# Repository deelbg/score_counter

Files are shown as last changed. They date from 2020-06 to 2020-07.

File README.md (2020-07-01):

# score_counter

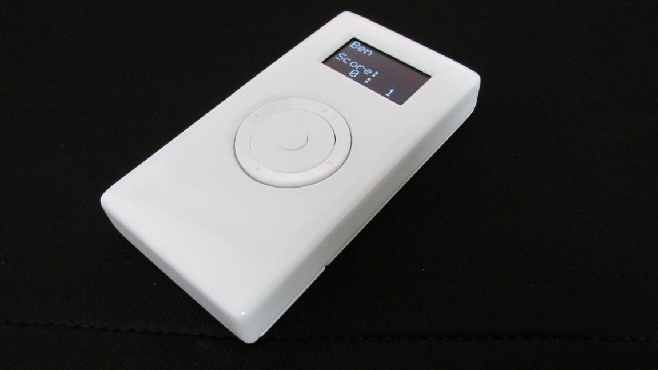
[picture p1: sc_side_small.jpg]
Score Counter


[Also available on my online store.](https://www.tindie.com/stores/deyantodorov/)

  Board games Score Counter is a device meant to be used for keeping the score for up to four players when playing board games like Scrabble etc. The numbers of players is selectable through the settings menu. Names up to ten characters long can be entered for each player.
  For each player an accumulated score is stored, which is the total amount of points up to the current moment in the game, and the points from the current round are entered using a rotary encoder or the Up and Down arrow keys. When OK is pressed the point from the current round are added to the total amount. 
  More detailed explanation and screenshot might be found in the User manual [HERE](https://github.com/deelbg/score_counter/blob/master/sc_manual.pdf) or on my web site [HERE](https://deyantodorov.com/2020/06/24/board-games-score-counter/)
  
Main features.
* Small size (10cm / 5.5cm / 1.7cm). 
* Battery powered. Runs on two AAA batteries.
* 1.3” OLED screen.
* Controlled via five buttons and a rotary switch.
* 3D printed enclosure.
* Energy independent memory to store settings and player names.

In the **/firmware** directory is located the firmware. It uses the drivers from my [SSD1306_SH1106_i2c_text_display](https://github.com/deelbg/SSD1306_SH1106_i2c_text_display) and [hal_lib_avr_cpp](https://github.com/deelbg/hal_lib_avr_cpp) repositories. 
The device is based on a Attiny861 microcontroller.

There is a makefile included. Run the folowing:
* make - to build the project
* clean - to delete object files
* size - to see the used RAM and flash.
* flash - to write the .hex file to the microcontroller. Using avrdude and a usbasp programmer.
* eeprom - to write the eeprom.
* fuse - to write the fuses.

In the **/hardware** directory is located the hardware project for EagleCad and a KiCad export. 
**NOTE:** A 10kOhm pullup resistor needs to be added to the OK button (the one right in the center).  

In the **/enclosure** directory is located a FreeCad project containig the enclosure. The 3 parts are also exported in .obj files that can be directly imported in Cura and sliced for 3d printing.

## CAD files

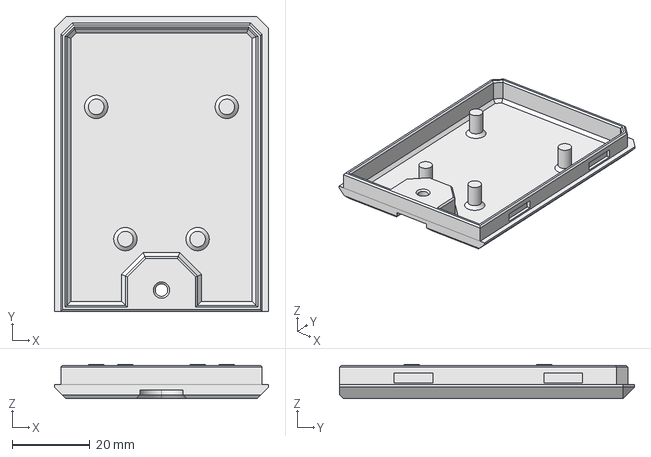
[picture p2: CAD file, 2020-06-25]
enclosure/enclosure_back.fcstd
55.0 x 75.8 x 8.85 mm

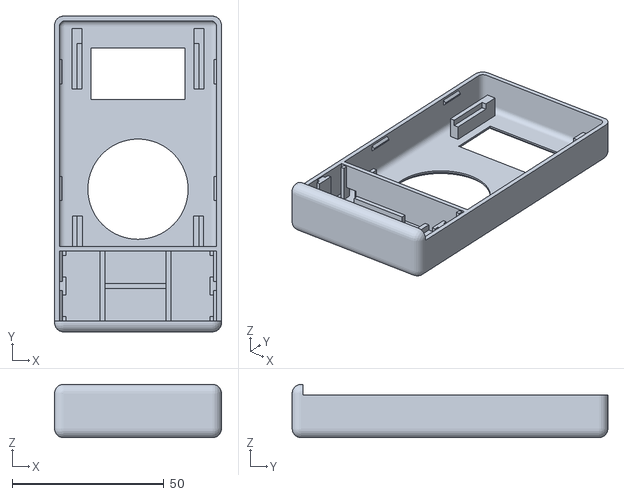
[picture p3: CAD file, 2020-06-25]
enclosure/front_filets.obj
55.0 x 104.0 x 17.6

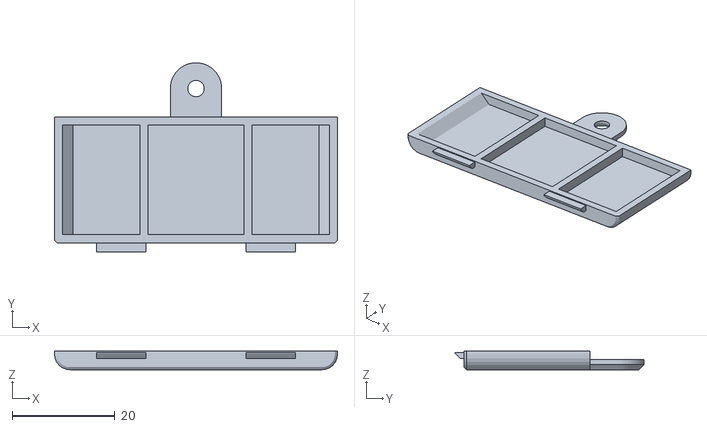
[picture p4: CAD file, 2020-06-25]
enclosure/lid_fillet.obj
55.0 x 36.8 x 3.60

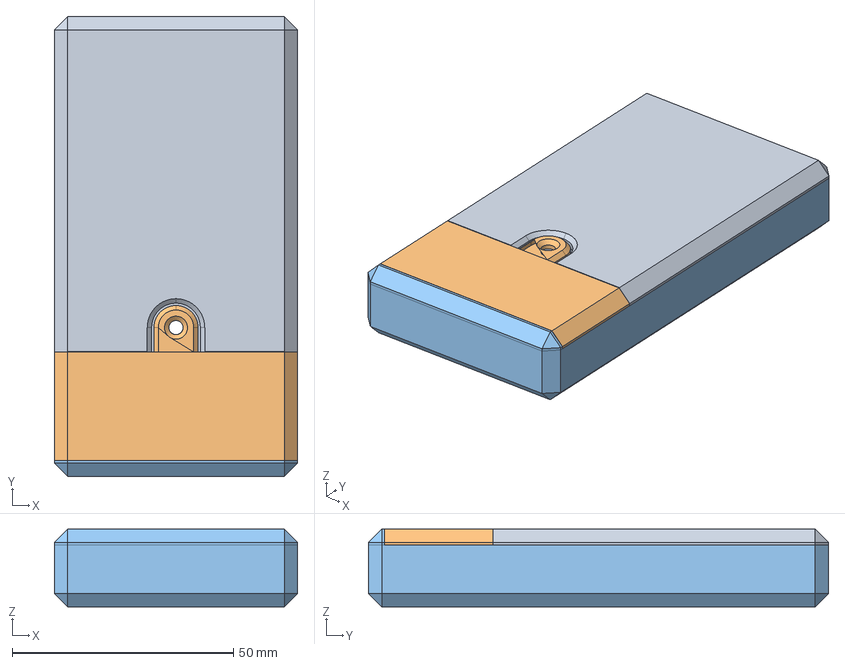
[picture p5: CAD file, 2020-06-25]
enclosure/enclosure.fcstd
55.0 x 104.0 x 17.6 mm

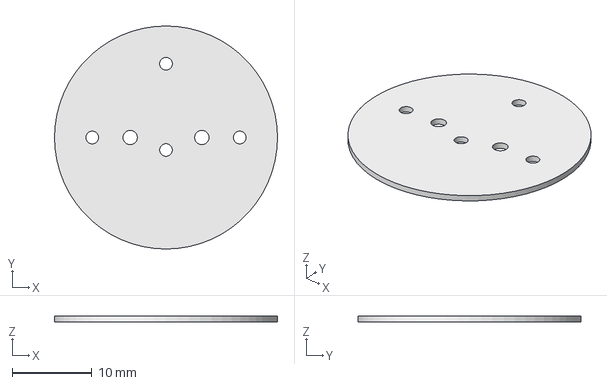
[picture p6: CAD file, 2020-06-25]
enclosure/button_spacer.fcstd
28.0 x 28.0 x 0.7 mm

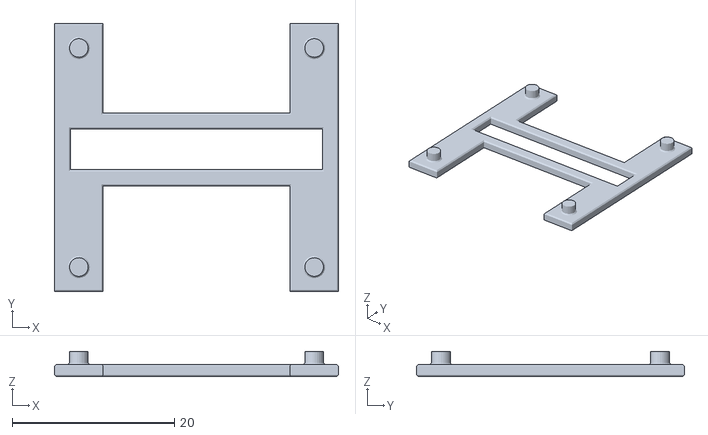
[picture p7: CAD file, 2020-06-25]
enclosure/display_holder.obj
35.0 x 33.0 x 3.10

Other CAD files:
enclosure/battery_lid_fillet.fcstd
enclosure/back.obj
enclosure/front.obj
enclosure/enclosure_front.fcstd
enclosure/SC_display_holder13inch.fcstd
enclosure/back_fillet.obj
enclosure/battery_lid.fcstd
enclosure/lid.obj
enclosure/enclosure_front_fillets.fcstd
enclosure/enclosure_back_fillets.fcstd
enclosure/button_spacer.obj

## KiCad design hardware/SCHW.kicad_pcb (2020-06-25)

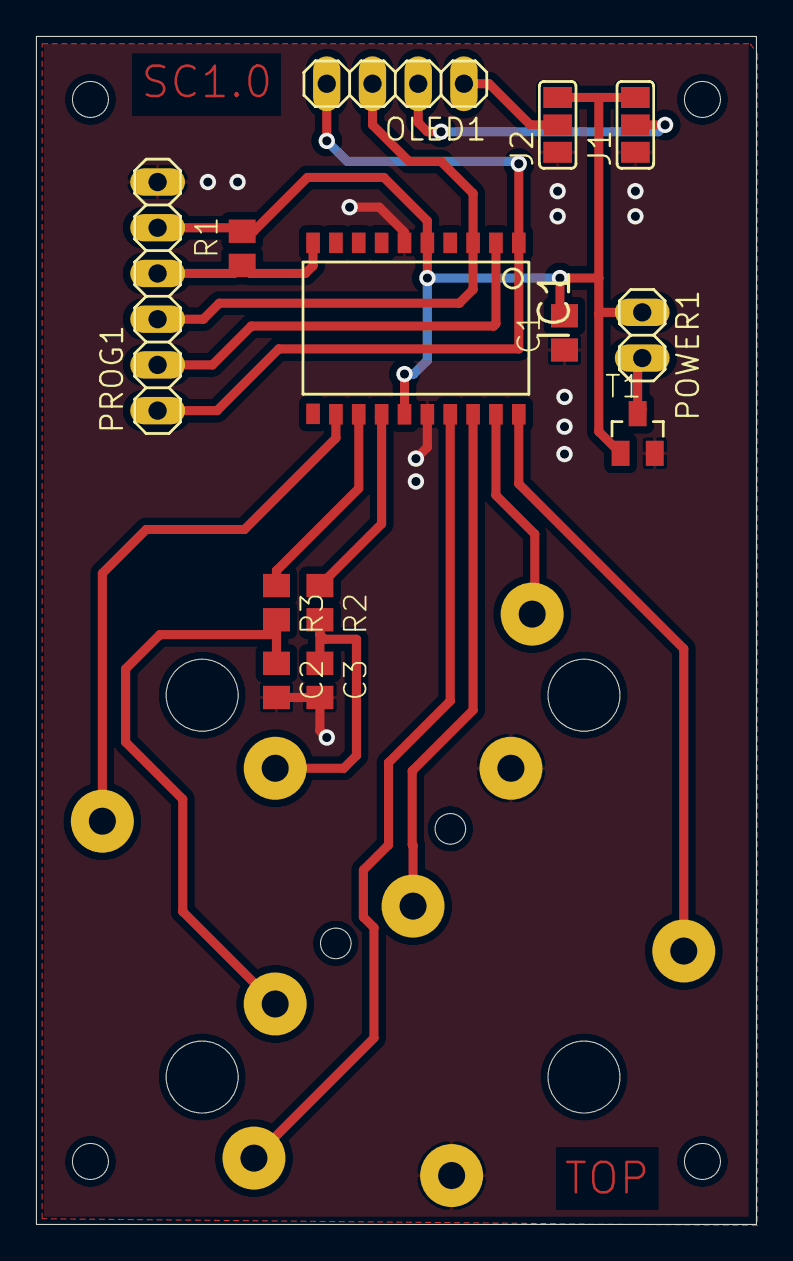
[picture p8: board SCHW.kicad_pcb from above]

Board: 2 copper layers, 40.0 x 66.0 mm, 18 parts (0 on the bottom side), 17 nets.

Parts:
@HOLE0, @HOLE1, @HOLE2, @HOLE3: (no value)
BUTTONS1: ENCODER_ARROWS
C1, C2, C3: 100n; C0805
IC1: TINY26S; SO20L
J1, J2: SJ2W; SJ_2
OLED1: PINHD-1X4; 1X04
POWER1: PINHD-1X2; 1X02
PROG1: PINHD-1X6; 1X06
R1: 10k; R0805
R2, R3: 10K; R0805
T1: AP2306GN_MOSFETSOT23; SOT23

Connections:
/SCHW_1/DOWN: BUTTONS1.S2, IC1.17
/SCHW_1/ENC_A: BUTTONS1.A, C2.1, R3.2
/SCHW_1/ENC_A_RAW: IC1.13, R3.1
/SCHW_1/ENC_B: BUTTONS1.B, C3.1, R2.2
/SCHW_1/ENC_B_RAW: IC1.14, R2.1
/SCHW_1/LEFT: BUTTONS1.S5, IC1.20
/SCHW_1/MISO: IC1.2, PROG1.2
/SCHW_1/MOSI/SDA: IC1.1, OLED1.4, PROG1.1
/SCHW_1/OK: BUTTONS1.S1, IC1.18
/SCHW_1/RESET: IC1.10, PROG1.4, R1.1
/SCHW_1/RIGHT: BUTTONS1.S3, IC1.12
/SCHW_1/SCK: IC1.3, OLED1.3, PROG1.3
/SCHW_1/UP: BUTTONS1.S4, IC1.19
GND: BUTTONS1.COM_A, BUTTONS1.COM_B, C1.1, C2.2, C3.2, IC1.6, IC1.16, J1.1, J2.1, PROG1.6, T1.2
unnamed: J1.2, OLED1.2
unnamed: J2.2, OLED1.1
VCC: C1.2, IC1.5, IC1.15, J1.3, J2.3, POWER1.1, PROG1.5, R1.2

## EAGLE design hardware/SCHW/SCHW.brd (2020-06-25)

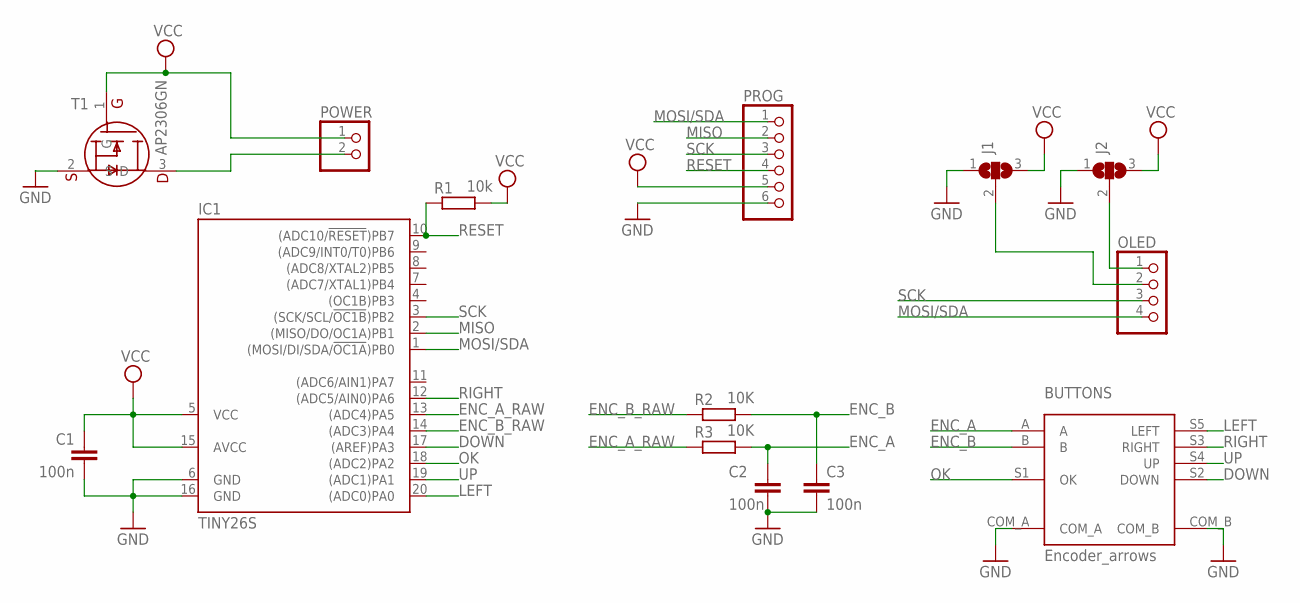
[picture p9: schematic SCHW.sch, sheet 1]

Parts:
BUTTONS: ENCODER_ARROWS
C1, C2, C3: 100n; C0805
IC1: TINY26S; SO20L
J1, J2: SJ2W; SJ_2
OLED: PINHD-1X4; 1X04
POWER: PINHD-1X2; 1X02
PROG: PINHD-1X6; 1X06
R1: 10k; R0805
R2, R3: 10K; R0805
T1: AP2306GN_MOSFETSOT23; SOT23

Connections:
DOWN: BUTTONS.S2 (DOWN), IC1.17 ((AREF)PA3)
ENC_A: BUTTONS.A, C2.1, R3.2
ENC_A_RAW: IC1.13 ((ADC4)PA5), R3.1
ENC_B: BUTTONS.B, C3.1, R2.2
ENC_B_RAW: IC1.14 ((ADC3)PA4), R2.1
GND: BUTTONS.COM_A, BUTTONS.COM_B, C1.1, C2.2, C3.2, IC1.6 (GND), IC1.16 (GND), J1.1, J2.1, PROG.6, T1.2 (S)
LEFT: BUTTONS.S5 (LEFT), IC1.20 ((ADC0)PA0)
MISO: IC1.2 ((MISO/DO/OC1A)PB1), PROG.2
MOSI/SDA: IC1.1 ((MOSI/DI/SDA/!OC1A!)PB0), OLED.4, PROG.1
unnamed: POWER.2, T1.3 (D)
unnamed: J2.2, OLED.1
unnamed: J1.2, OLED.2
OK: BUTTONS.S1 (OK), IC1.18 ((ADC2)PA2)
RESET: IC1.10 ((ADC10/!RESET!)PB7), PROG.4, R1.1
RIGHT: BUTTONS.S3 (RIGHT), IC1.12 ((ADC5/AIN0)PA6)
SCK: IC1.3 ((SCK/SCL/!OC1B!)PB2), OLED.3, PROG.3
UP: BUTTONS.S4 (UP), IC1.19 ((ADC1)PA1)
VCC: C1.2, IC1.5 (VCC), IC1.15 (AVCC), J1.3, J2.3, POWER.1, PROG.5, R1.2, T1.1 (G)

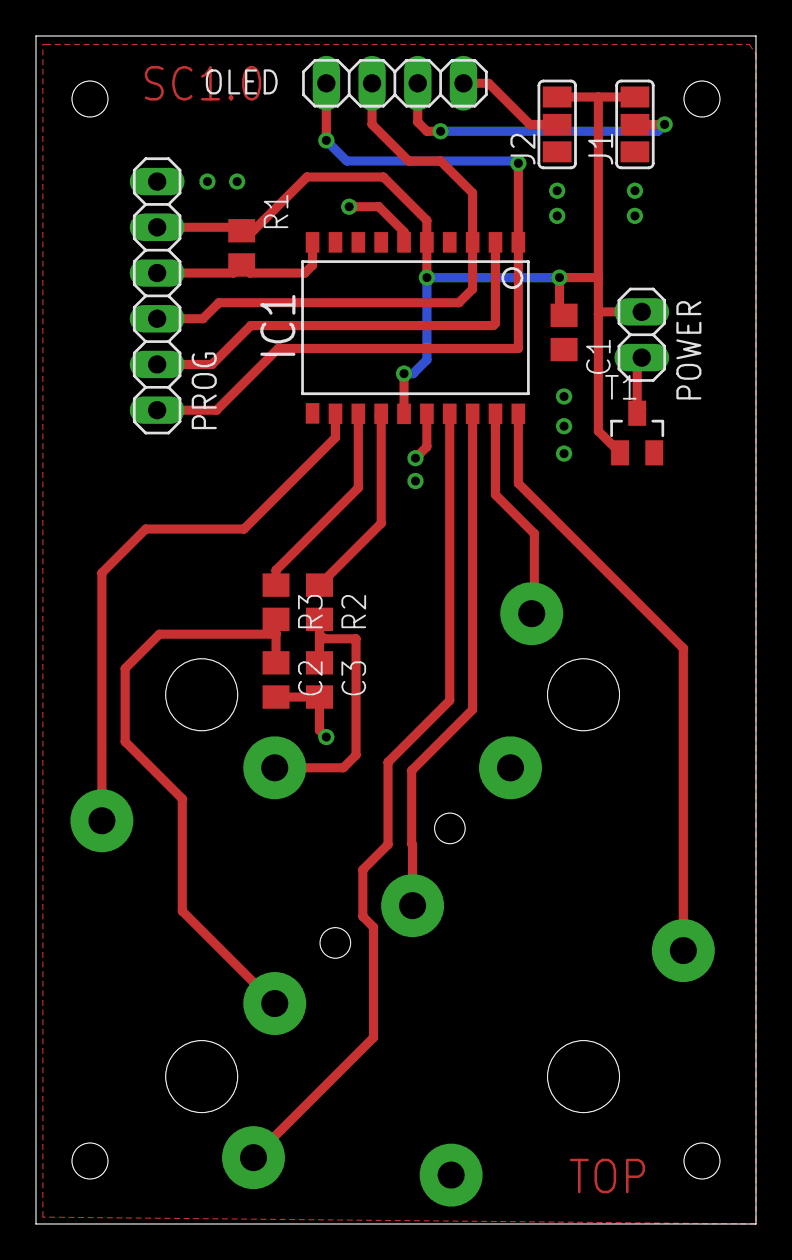
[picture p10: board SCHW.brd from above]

Board: 2 copper layers, 40.0 x 66.0 mm, 14 parts (1 on the bottom side), 18 nets.

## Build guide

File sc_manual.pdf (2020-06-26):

# Score counter v1.0:

User manual.

### Author : Deyan Todorov

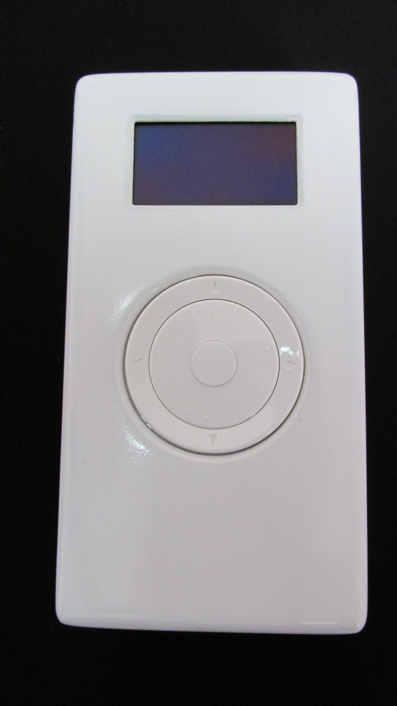
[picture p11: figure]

## Table of Contents

1. Purpose and intended use of the device.

Score Counter is a device meant to be used for keeping the score for up to four players when playing board games like Scrabble etc. The numbers of players is selectable through the settings menu. Names up to ten characters long can be entered for each player.
For each player an accumulated score is stored, which is the total amount of pints up to the current moment in the game, and the points from the current round are entered using a rotary encoder or the Up and Down arrow keys. When OK is pressed the point from the current round are added to the total amount. More detailed explanation and screenshot might be found in chapter 3. How to use.
2. Main features.
- Small size (10cm / 5.5cm / 1.7cm).
- Battery powered. Runs on two AAA batteries.
- 1.3” OLED screen.
- Controlled via five buttons and a rotary switch.
- 3D printed enclosure.
- Energy independent memory to store settings and player names.
3. How to use.

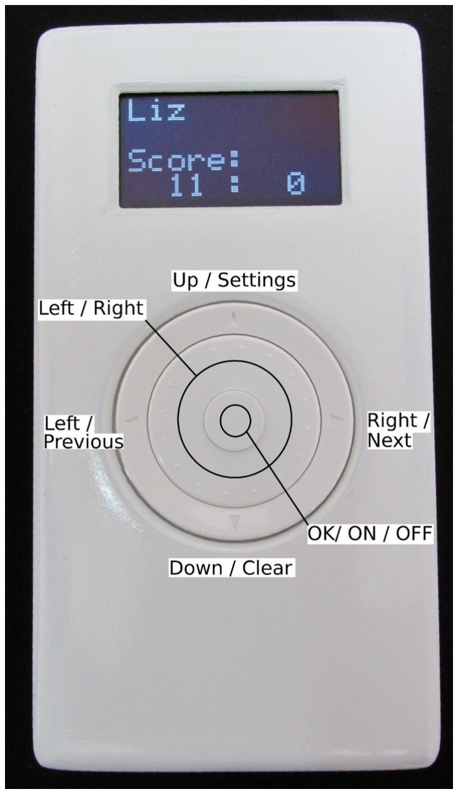
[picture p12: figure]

3.1. Controls.

The score counter is controlled via five buttons and a rotary switch on the picture on the right the location of the controls is shown.
There are four arrow buttons on the outermost ring, there is one button in the center, that is the OK/ON/OFF button and finally there is the rotary switch which is located between the button already mentioned.
Each button has different function when the device is in configuration mode and when it is in normal mode. The buttons function is described below in the screens description.
The device is switched on by pressing the ON/OFF button.
To switch it off, hold the ON/OFF button for 3 seconds. This will clear the score for all players as well.
If there was no activity on any of the buttons for 10 seconds, the display will be dimmed out to save battery and after 10 minutes of no activity the device will switch off, but will keep the scores and when switched on again will display them.

3.2. Screens.

Here all possible screens of the device are described and for each screens the function of the different controls is listed as well.
3.2.1. Main screen.
When the device is switched on the screen with the score for Player 1
will be shown. This kind of screen shows player’s scores and is the one used in the device’s normal mode.
It Has three lines:
- Player’s name
- Fixed text - “Score:”

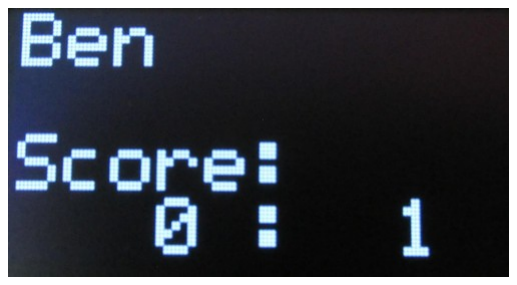
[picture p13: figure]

- The total score for the player is shown in the left half of the line and the new points to be added are shown in the right half of the line.
The new points are increased or decreased using the rotary switch or the left and right arrows. When the desired number of points is selected the OK button is pressed and the new points are added to the player’s total score and the screen is switched to display the next player if there are more than one players.
3.2.2. Settings screens.
3.2.2.1. Select language.
To enter settings mode hold the UP arrow for 3 seconds. Then the first settings screen is displayed which is for selecting the language of the interface. The Score Counter supports two languages English and Bulgarian. The desired language is selected using the rotary switch and confirmed by pressing the OK button. In this manual only the english interface is shown on the screenshots.
3.2.2.2. Number of players.
After selecting the language, the number of players is to be selected. The maximum number of players is four. The Desired number is set using the rotary switch and confirmed by pressing the OK button.

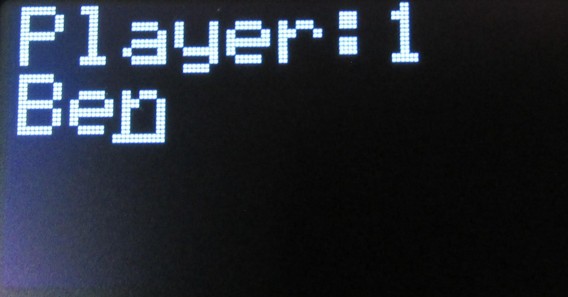
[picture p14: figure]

3.2.2.3. Player’s name.
Each player might be named. The default names are P1 to P4. After selecting the number of players and confirming with OK, a name editing screen for Player 1 is shown. When the desired name is entered, it is confirmed by button OK and the name edit screen for the next player is opened. This will be done between 1 and 4 times, depending on the already selected number of players.

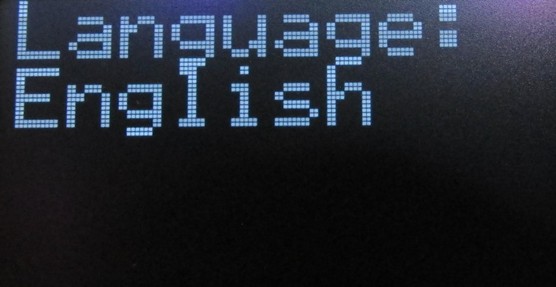
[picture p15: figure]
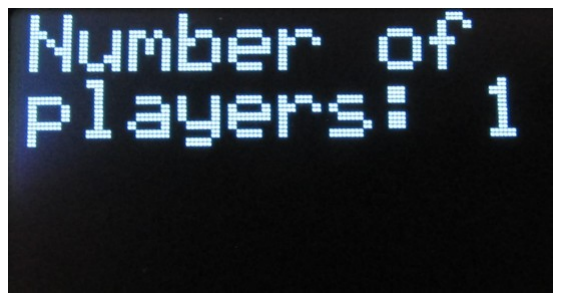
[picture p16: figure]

The name is selected using the rotary switch and the Left and Right arrows. A letter is selected using the rotary switch. The possible characters are numbers from 0 to 9, small and capital A to Z, digits and small and capital cyrillic letters. When a letter is selected, the cursor is moved to another position using the Left and Right arrows. Another
letter might be selected again using the rotary switch. The Maximum
number of character per name is ten.

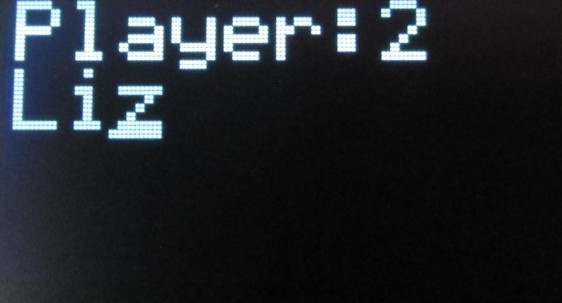
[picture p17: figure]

Pressing the OK button confirms the name and switches to editing the name of the next player. If the selected number of players is reached, pressing OK will save all changes in the devices non volatile memory and will go back to normal mode, showing the first player’s points screen .

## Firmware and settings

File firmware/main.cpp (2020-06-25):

// =============================================================================
// Fuse settings to use while programming
// SELFPRGEN = [ ]  - flash self program enable
// RSTDISBL = [ ]   - reset pin disable
// DWEN = [ ]       - debug wire enable
// SPIEN = [X]      - SPI programing enable
// WDTON = [ ]      - watch dog on in all modes
// EESAVE = [X]     - save eeprom on chip erase
// BODLEVEL = 1V8   - brown out detector voltage
// CKDIV8 = [X]     - clock devider 
// CKOUT = [ ]      - clock out pin enable
// SUT_CKSEL = INTRCOSC_8MHZ_6CK_14CK_0MS - clock source

// EXTENDED = 0xFF (valid)
// HIGH = 0xD6 (modified)
// LOW = 0x42 (valid)
// =============================================================================
#define SC_VERSION_MAJOR 1
#define SC_VERSION_MINOR 0
#define SC_VERSION_PATCH 0

#include <stdint.h>
#include <avr/io.h>
#include <avr/wdt.h> 
#include <avr/interrupt.h>
#include "timer.h"
#include "hal_avr_io.h"
#include "hal_avr_i2c.h"
#include "hal_encoder.h"
#include "SSD1306_SH1106_i2c_text_display.h"
#include "score_counter.h"

static const uint8_t  OLED_ADDRESS  = 0x3Cu;

c_io                        g_io          = c_io();
c_i2c                       g_i2c         = c_i2c();
c_timer                     g_timer_1_s   = c_timer();
c_SSD1306_SH1106_i2c        g_display     = c_SSD1306_SH1106_i2c(g_i2c, OLED_ADDRESS);
c_encoder                   g_encoder     = c_encoder(g_io, true,  g_io.INPUT_ENCODER_A, g_io.INPUT_ENCODER_B);
c_score_counter             g_counter     = c_score_counter(g_io, g_encoder, g_display);

void mcu_init(void);
void main_loop(void);
void timer_0_init(void);


int main(void)
{    
    mcu_init();
    main_loop();
}


void mcu_init()
{
    // Power Reduction Register
    // PRR register
    // +----------------------------+-----+
    // |Timer/counter 0 ------------| ON  |
    // |USI - used for I2C ---------| ON  |
    // |Brown-out Detector ---------| ON  |
    // |Internal Voltage Reference -| ON  |
    // |Watchdog Timer -------------| ON  |
    // |Port Pins ------------------| ON  |
    // +----------------------------+-----+
    // |Timer Counter 1 ------------| OFF |
    // |Analog Comparator ----------| OFF |
    // |Analog to Digital Converter | OFF |    
    // +----------------------------+-----+
    PRR = (1 << PRADC) | (1 << PRTIM1);

    // Set prescaler to 1:2 to get 4Mhz system clock.
    CLKPR = (1u << CLKPCE);
    CLKPR = (0u << CLKPS3) | (0u << CLKPS2) | (0u << CLKPS1) | (1u << CLKPS0);

    // Enable watch dog timer at 4 seconds.
    wdt_enable(WDTO_4S);

    timer_0_init();
    g_i2c.init();
}


void main_loop()
{
    while (1) 
    {
        wdt_reset();

        g_counter.score_counter();
        
        if (g_timer_1_s.expired())
        {
            g_counter.timer_tick();
            g_timer_1_s.start(1000u);
        }
    }
}


void timer_0_init(void)
{
    cli();              //stop interrupts

    // In Clear Timer on Compare or CTC mode
    // 4 000 000 hz / (64 * 63) = 1000Hz (1mS)
    OCR0A   = 63u;      // Timer 0 Output Compare Register A, low: 50 

    TCCR0A  = 0x01u;    // Timer/Counter 0 Control Register A: 
                        // STS0 - Clear Timer on Compare Match (CTC) mode
    
    TCCR0B  = 0x03u;    // Timer/Counter 0 Control Register B: 
                        // CS01 - 1:8 prescaler
    
    TIFR    |= 0x1Bu;   // Timer/Counter 0 Interrupt Flag Register: 
                        // OCF0A | OCF0B | TOV0 | ICF0 Clear all interrupt flags 
    
    TIMSK   = 0x10u;    // Timer/Counter0 Interrupt Mask Register:
                        // OCIE0A - Timer/Counter0 Output Compare Match A 
                        // Interrupt Enable
    sei();              //allow interrupts
}


//timer0 interrupt every 1 ms (1kHz)
ISR(TIMER0_COMPA_vect)
{
    static uint8_t counter_10ms = 0u;
    
    if (0u == counter_10ms)
    {
        g_io.debaunce();  

        counter_10ms = 10u;
    }

    counter_10ms--;

    g_encoder.scan(); 
    g_timer_1_s.decrement();
}

ISR(INT1_vect) 
{
    // No need for any action here. 
    // The interrupt only wakes up MCU from sleep.
}

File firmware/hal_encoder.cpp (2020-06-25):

#include <stdint.h>
#include "hal_avr_io.h"
#include "hal_encoder.h"


c_encoder::c_encoder(c_io & ref_io, bool use_raw_input, uint8_t encoder_pin_a, uint8_t encoder_pin_b) :
                    r_io(ref_io), use_raw(use_raw_input), pin_a(encoder_pin_a), pin_b(encoder_pin_b),
                    pulse_number_left(0u), pulse_number_right(0u)
{

}


void c_encoder::scan(void)
{
    static bool pin_a_high_old = false;
    bool pin_a_high = use_raw ? r_io.input_get_raw(pin_a) : r_io.input_get(pin_a);
    bool pin_b_high = use_raw ? r_io.input_get_raw(pin_b) : r_io.input_get(pin_b);

    if (pin_a_high && !pin_a_high_old)
    {
        if (pin_b_high)
        {
            if (0xFFFFu > pulse_number_left)
            {
                pulse_number_left++;
            }
        }
        else
        {
            if (0xFFFFu > pulse_number_right)
            {
                pulse_number_right++;
            }
        }

    }

    if (!pin_a_high && pin_a_high_old)
    {
        if (!pin_b_high)
        {
            if (0xFFFFu > pulse_number_left)
            {
                pulse_number_left++;
            }
        }
        else
        {
            if (0xFFFFu > pulse_number_right)
            {
                pulse_number_right++;
            }
        }

    }

    pin_a_high_old = pin_a_high;
}


uint8_t c_encoder::get_pulses_left(bool reset_pulses)
{
    uint8_t result = pulse_number_left;
    
    if (reset_pulses)
    {
        pulse_number_left = 0u;
    }

    return result;
}


uint8_t c_encoder::get_pulses_right(bool reset_pulses)
{
    uint8_t result = pulse_number_right;
    
    if (reset_pulses)
    {
        pulse_number_right = 0u;
    }

    return result;
}


void c_encoder::set_pulses_left(uint8_t pulses)
{
    pulse_number_left = pulses;
}


void c_encoder::set_pulses_right(uint8_t pulses)
{
    pulse_number_right = pulses;
}
